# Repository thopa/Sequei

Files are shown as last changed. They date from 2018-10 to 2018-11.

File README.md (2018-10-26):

# Sequei
Arduino analog pot controlled drum machine based on the concept of Mutable Instrument's Anushri and Grids drum sequencer.

Features:

4 trigger drum Channels with Density and X Y drum mapping (see Mutable Instruments Grids)
Clock Sync
Control Voltage over Map X and Map Y

Special thanks to:
Olivier Gillet (olivier@mutable-instruments.net)
Honza Hrubes /aka ashimoke ashimoke@gmail.com
Geert @ http://Goltstein.nl
Darwin Grosse @  (www.20objects.com).

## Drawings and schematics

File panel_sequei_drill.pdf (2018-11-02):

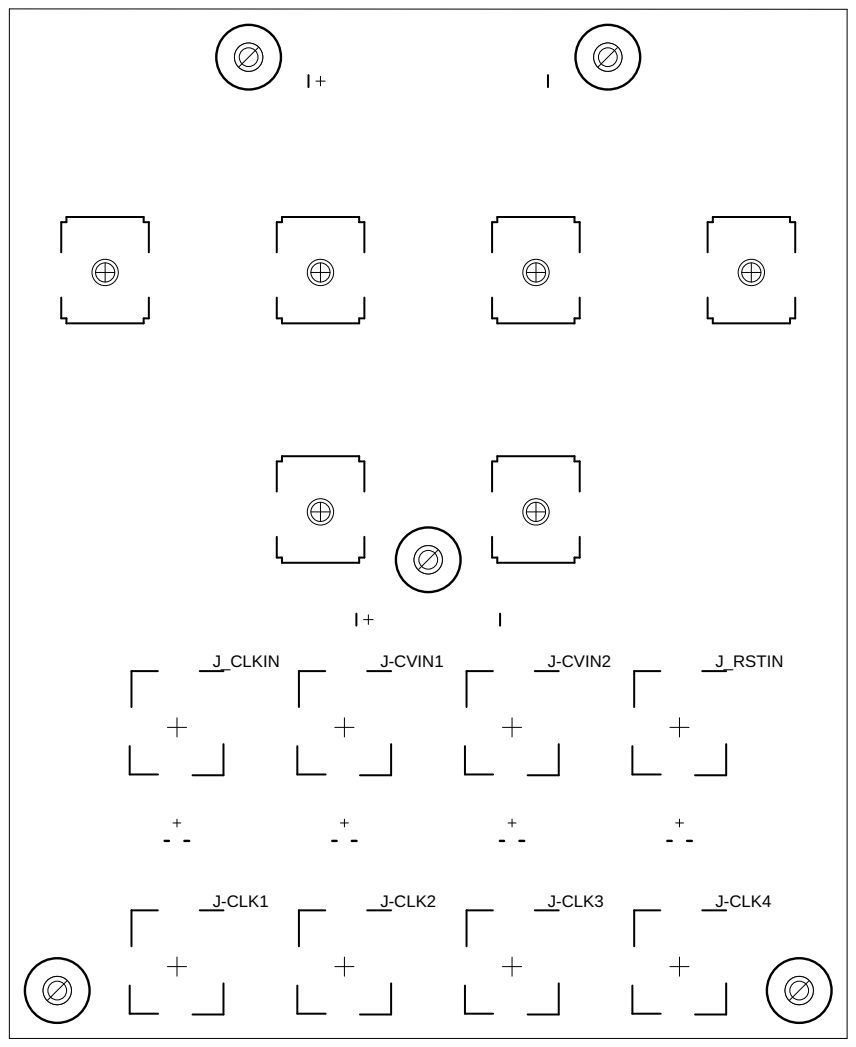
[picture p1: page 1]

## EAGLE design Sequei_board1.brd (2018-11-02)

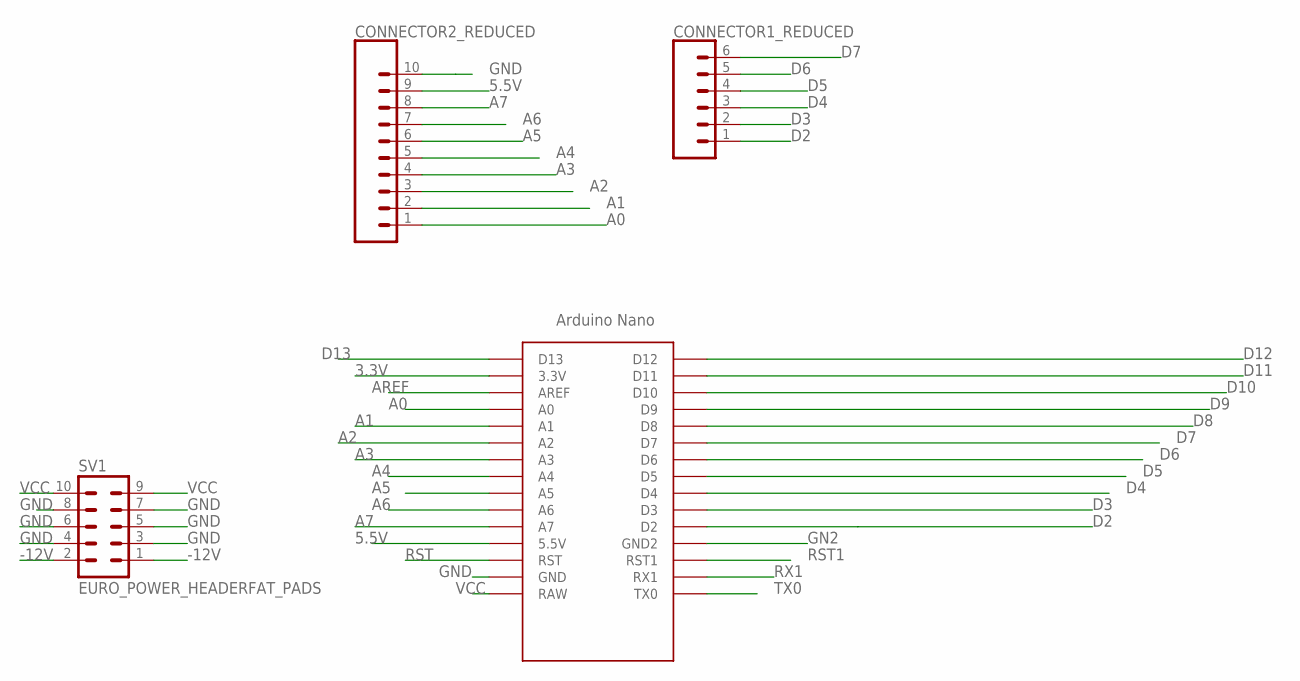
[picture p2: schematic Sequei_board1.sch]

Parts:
CONNECTOR1_REDUCED: CONN_06LONGPADS; 1X06_LONGPADS
CONNECTOR2_REDUCED: CONN_10_LONGPADS10_LONGPADS; 1X10_LONGPADS
SV1: EURO_POWER_HEADERFAT_PADS; EURO_PWR_HEADER_FAT
U$1: NANO

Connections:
3.3V: U$1.3.3V
5.5V: CONNECTOR2_REDUCED.9, U$1.5V (5.5V)
-12V: SV1.1, SV1.2
A0: CONNECTOR2_REDUCED.1, U$1.A0
A1: CONNECTOR2_REDUCED.2, U$1.A1
A2: CONNECTOR2_REDUCED.3, U$1.A2
A3: CONNECTOR2_REDUCED.4, U$1.A3
A4: CONNECTOR2_REDUCED.5, U$1.A4
A5: CONNECTOR2_REDUCED.6, U$1.A5
A6: CONNECTOR2_REDUCED.7, U$1.A6
A7: CONNECTOR2_REDUCED.8, U$1.A7
AREF: U$1.AREF
D2: CONNECTOR1_REDUCED.1, U$1.D2
D3: CONNECTOR1_REDUCED.2, U$1.D3
D4: CONNECTOR1_REDUCED.3, U$1.D4
D5: CONNECTOR1_REDUCED.4, U$1.D5
D6: CONNECTOR1_REDUCED.5, U$1.D6
D7: CONNECTOR1_REDUCED.6, U$1.D7
D8: U$1.D8
D9: U$1.D9
D10: U$1.D10
D11: U$1.D11
D12: U$1.D12
D13: U$1.D13
GN2: U$1.GND1 (GND2)
GND: CONNECTOR2_REDUCED.10, SV1.3, SV1.4, SV1.5, SV1.6, SV1.7, SV1.8, U$1.GND
RST: U$1.RST
RST1: U$1.RST1
RX1: U$1.RX1
TX0: U$1.TX0
VCC: SV1.9, SV1.10, U$1.RAW

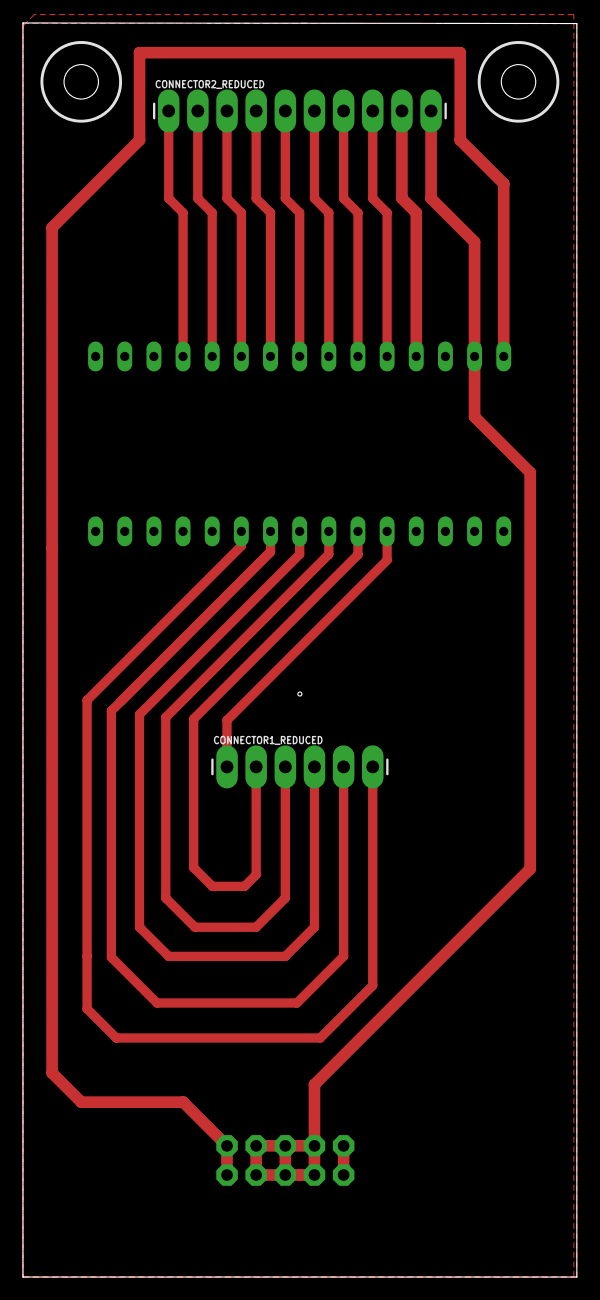
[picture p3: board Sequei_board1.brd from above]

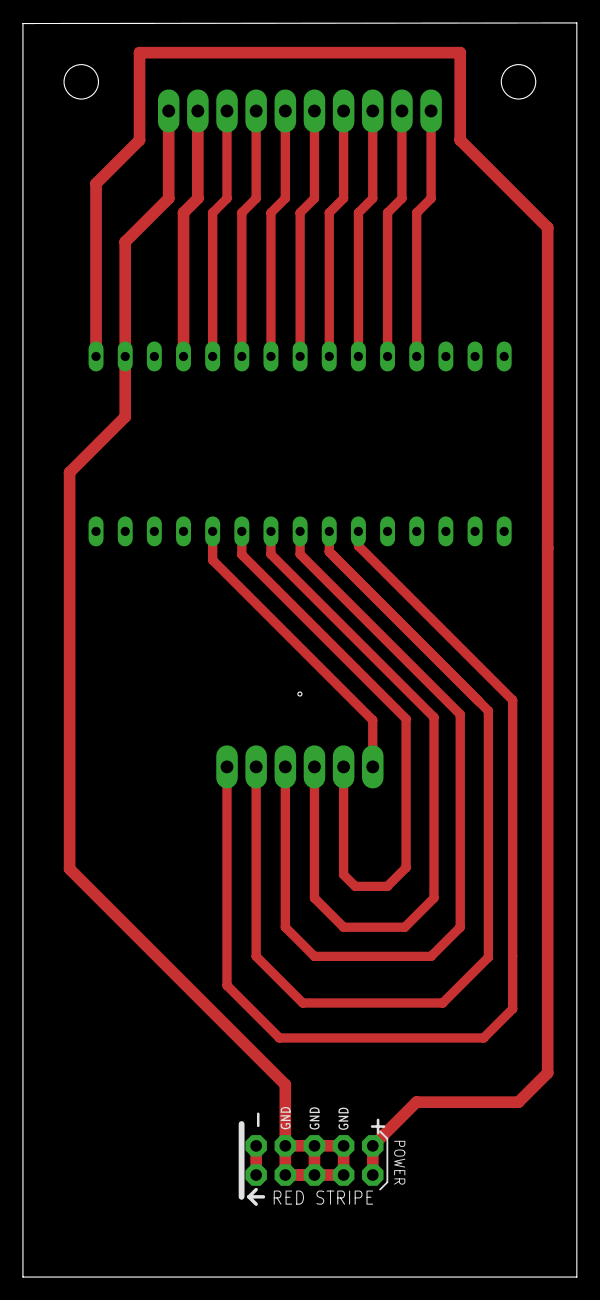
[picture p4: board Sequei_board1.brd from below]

Board: 2 copper layers, 48.3 x 109.3 mm, 6 parts (2 on the bottom side), 18 nets.

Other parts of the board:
H1, H2: DRIL-3

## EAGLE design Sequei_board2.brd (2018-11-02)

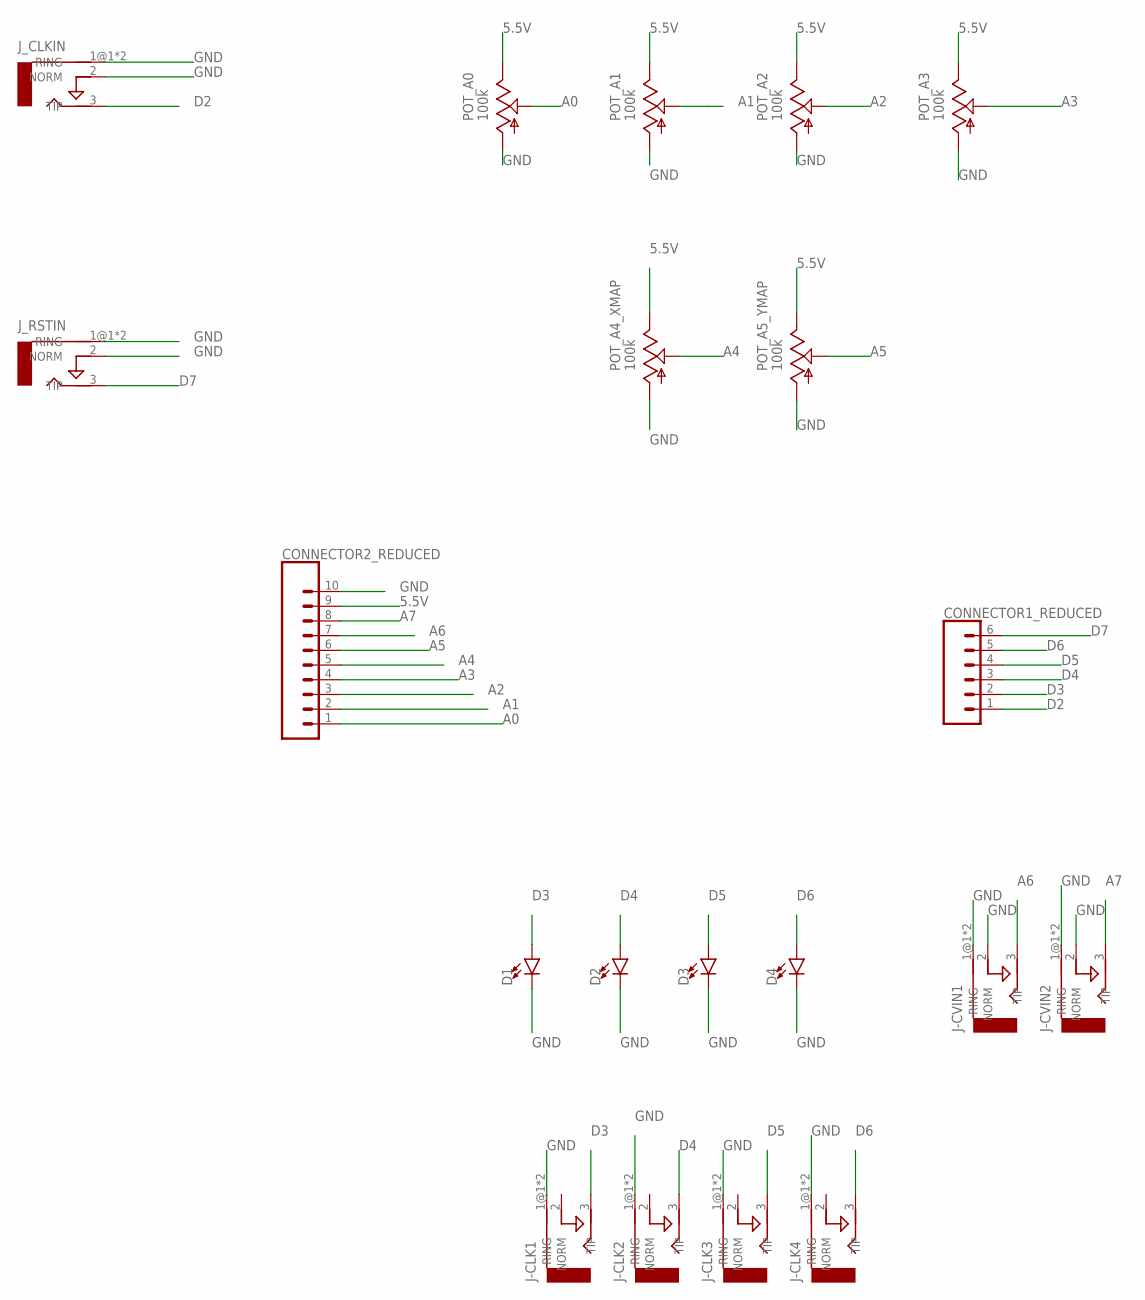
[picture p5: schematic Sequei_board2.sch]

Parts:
CONNECTOR1_REDUCED: CONN_06LONGPADS; 1X06_LONGPADS
CONNECTOR2_REDUCED: CONN_10_LONGPADS10_LONGPADS; 1X10_LONGPADS
D1, D2, D3, D4: LED-3MM-NO_SILK; LED_3MM-NS
J-CLK1, J-CLK2, J-CLK3, J-CLK4: AUDIO-JACKERTHENVAR; ERTHENVAR-JACK
J-CVIN1, J-CVIN2: AUDIO-JACKERTHENVAR; ERTHENVAR-JACK
J_CLKIN: AUDIO-JACKERTHENVAR; ERTHENVAR-JACK
J_RSTIN: AUDIO-JACKERTHENVAR; ERTHENVAR-JACK
POT_A0, POT_A1, POT_A2, POT_A3, POT_A4_XMAP, POT_A5_YMAP: 100k; 9MM_SNAP-IN_POT

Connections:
5.5V: CONNECTOR2_REDUCED.9, POT_A0.3 (E), POT_A1.3 (E), POT_A2.3 (E), POT_A3.3 (E), POT_A4_XMAP.3 (E), POT_A5_YMAP.3 (E)
A0: CONNECTOR2_REDUCED.1, POT_A0.2 (S)
A1: CONNECTOR2_REDUCED.2, POT_A1.2 (S)
A2: CONNECTOR2_REDUCED.3, POT_A2.2 (S)
A3: CONNECTOR2_REDUCED.4, POT_A3.2 (S)
A4: CONNECTOR2_REDUCED.5, POT_A4_XMAP.2 (S)
A5: CONNECTOR2_REDUCED.6, POT_A5_YMAP.2 (S)
A6: CONNECTOR2_REDUCED.7, J-CVIN1.3 (TIP)
A7: CONNECTOR2_REDUCED.8, J-CVIN2.3 (TIP)
D2: CONNECTOR1_REDUCED.1, J_CLKIN.3 (TIP)
D3: CONNECTOR1_REDUCED.2, D1.A, J-CLK1.3 (TIP)
D4: CONNECTOR1_REDUCED.3, D2.A, J-CLK2.3 (TIP)
D5: CONNECTOR1_REDUCED.4, D3.A, J-CLK3.3 (TIP)
D6: CONNECTOR1_REDUCED.5, D4.A, J-CLK4.3 (TIP)
D7: CONNECTOR1_REDUCED.6, J_RSTIN.3 (TIP)
GND: CONNECTOR2_REDUCED.10, D1.K (C), D2.K (C), D3.K (C), D4.K (C), J-CLK1.1@1 (RING), J-CLK1.1@2 (RING), J-CLK2.1@1 (RING), J-CLK2.1@2 (RING), J-CLK3.1@1 (RING), J-CLK3.1@2 (RING), J-CLK4.1@1 (RING), J-CLK4.1@2 (RING), J-CVIN1.1@1 (RING), J-CVIN1.1@2 (RING), J-CVIN1.2 (NORM), J-CVIN2.1@1 (RING), J-CVIN2.1@2 (RING), J-CVIN2.2 (NORM), J_CLKIN.1@1 (RING), J_CLKIN.1@2 (RING), J_CLKIN.2 (NORM), J_RSTIN.1@1 (RING), J_RSTIN.1@2 (RING), J_RSTIN.2 (NORM), POT_A0.1 (A), POT_A1.1 (A), POT_A2.1 (A), POT_A3.1 (A), POT_A4_XMAP.1 (A), POT_A5_YMAP.1 (A)

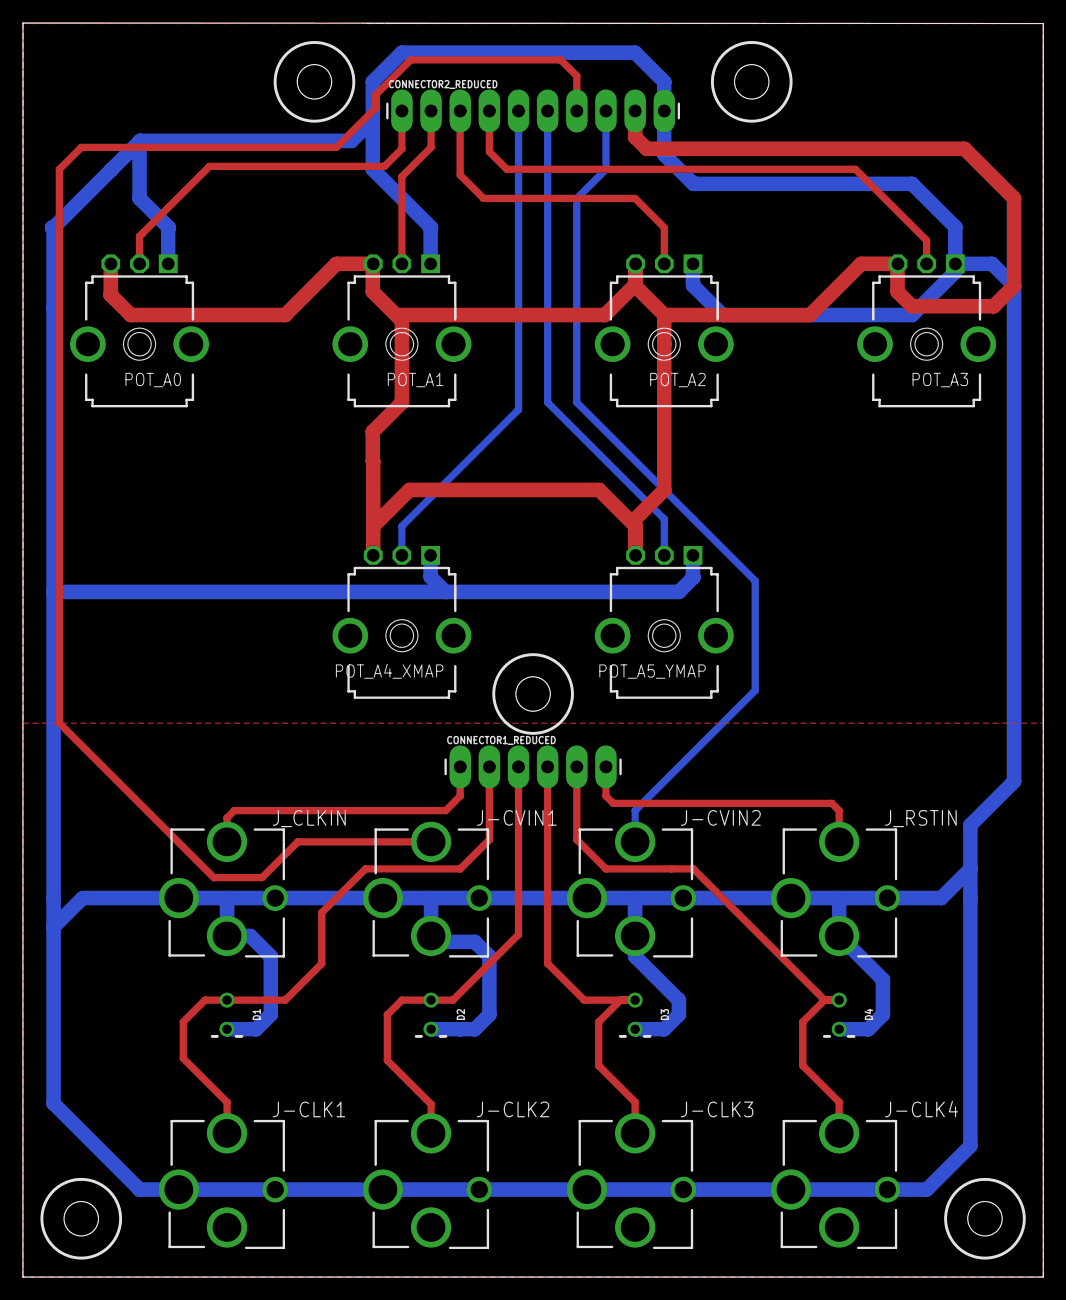
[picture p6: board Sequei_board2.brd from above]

Board: 2 copper layers, 88.9 x 109.3 mm, 25 parts (0 on the bottom side), 16 nets.

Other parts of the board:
H1, H2, H3, H4, H5: DRIL-3

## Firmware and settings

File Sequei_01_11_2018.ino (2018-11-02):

//Arduino Trigger Sequencer bases on Mutable Instruments Anushri and Grids by Thopa 2018 djthopa@djthopa.net
//
// 4 trigger Channels synced to Analog Clock

//Special thanks to:
//Olivier Gillet (olivier@mutable-instruments.net)

//Honza Hrubes /aka ashimoke ashimoke@gmail.com

//Geert @ http://Goltstein.nl

//Darwin Grosse @  (www.20objects.com).

///////////////////////////////////////////////////////////////////////////////////////////////////////////

// Controls:

//Bass drum density pot  ---> A0
//Snare drum density pot ---> A1
//HiHat density pot      ---> A2
//OhHat density pot      ---> A3

//X coordinate           ---> A4
//Y coordinate           ---> A5

//Control Voltage over X coordinate          ---> A6
//Control Voltage over Y coordinate          ---> A7
// TO DO :

// Add cv control over Density & X - Y Coordinates
// Reset seems to be not working properly


//// copied from grids

int BDcluster1[16] = {255, 0, 0, 0, 0, 0, 145, 0, 0, 0, 0, 0, 218, 0, 0, 0 };
int SDcluster1[16] = {72, 0, 36, 0, 182, 0, 0, 0, 109, 0, 0, 0, 72, 0, 0, 0 };
int HHcluster1[16] = {36, 0, 109, 0, 0, 0, 8, 0, 255, 0, 0, 0, 0, 0, 72, 0 };
int OHcluster1[16] = {0, 0, 182, 0, 0, 0, 36, 0, 218, 0, 0, 0, 145, 0, 0, 0 };

int BDcluster2[16] = {229, 0, 25, 0, 102, 0, 25, 0, 204, 0, 25, 0, 76, 0, 8, 0 };
int SDcluster2[16] = {255, 0, 8, 0, 51, 0, 25, 0, 178, 0, 25, 0, 153, 0, 127, 0 };
int HHcluster2[16] = {28, 0, 198, 0, 56, 0, 56, 0, 226, 0, 28, 0, 141, 0, 28, 0 };
int OHcluster2[16] = {28, 0, 170, 0, 28, 0, 28, 0, 255, 0, 113, 0, 85, 0, 85, 0 };

int BDcluster3[16] = {255, 0, 0, 0, 127, 0, 0, 0, 0, 0, 102, 0, 0, 0, 229, 0 };
int SDcluster3[16] = {0, 0, 178, 0, 204, 0, 0, 0, 76, 0, 51, 0, 153, 0, 25, 0 };
int HHcluster3[16] = {0, 0, 127, 0, 0, 0, 0, 0, 255, 0, 191, 0, 31, 0, 63, 0 };
int OHcluster3[16] = {0, 0, 95, 0, 0, 0, 0, 0, 223, 0, 0, 0, 31, 0, 159, 0 };

int BDcluster4[16] = {255, 0, 212, 0, 63, 0, 0, 0, 106, 0, 148, 0, 85, 0, 127, 0 };
int SDcluster4[16] = {191, 0, 21, 0, 233, 0, 0, 0, 21, 0, 170, 0, 0, 0, 42, 0 };
int HHcluster4[16] = {0, 0, 0, 0, 141, 0, 113, 0, 255, 0, 198, 0, 0, 0, 56, 0 };
int OHcluster4[16] = {0, 0, 85, 0, 56, 0, 28, 0, 226, 0, 28, 0, 170, 0, 56, 0 };

int BDcluster5[16] = {255, 0, 31, 0, 63, 0, 63, 0, 127, 0, 95, 0, 191, 0, 63, 0 };
int SDcluster5[16] = {223, 0, 31, 0, 159, 0, 63, 0, 31, 0, 63, 0, 95, 0, 31, 0 };
int HHcluster5[16] = {8, 0, 0, 0, 95, 0, 63, 0, 255, 0, 0, 0, 127, 0, 0, 0 };
int OHcluster5[16] = {8, 0, 0, 0, 159, 0, 63, 0, 255, 0, 223, 0, 191, 0, 31, 0 };

int BDcluster6[16] = {255, 0, 51, 0, 25, 0, 76, 0, 0, 0, 0, 0, 102, 0, 0, 0 };
int SDcluster6[16] = {204, 0, 229, 0, 0, 0, 178, 0, 0, 0, 153, 0, 127, 0, 8, 0 };
int HHcluster6[16] = {178, 0, 127, 0, 153, 0, 204, 0, 255, 0, 0, 0, 25, 0, 76, 0 };
int OHcluster6[16] = {102, 0, 51, 0, 0, 0, 0, 0, 229, 0, 25, 0, 25, 0, 204, 0 };

int BDcluster7[16] = {255, 0, 0, 0, 223, 0, 0, 0, 31, 0, 8, 0, 127, 0, 0, 0 };
int SDcluster7[16] = {95, 0, 0, 0, 159, 0, 0, 0, 95, 0, 63, 0, 191, 0, 0, 0 };
int HHcluster7[16] = {51, 0, 204, 0, 0, 0, 102, 0, 255, 0, 127, 0, 8, 0, 178, 0 };
int OHcluster7[16] = {25, 0, 229, 0, 0, 0, 76, 0, 204, 0, 153, 0, 51, 0, 25, 0 };

int BDcluster8[16] = {223, 0, 0, 0, 63, 0, 0, 0, 95, 0, 0, 0, 223, 0, 31, 0 };
int SDcluster8[16] = {255, 0, 0, 0, 159, 0, 0, 0, 127, 0, 31, 0, 191, 0, 31, 0 };
int HHcluster8[16] = {0, 0, 0, 0, 109, 0, 0, 0, 218, 0, 0, 0, 182, 0, 72, 0 };
int OHcluster8[16] = {8, 0, 36, 0, 145, 0, 36, 0, 255, 0, 8, 0, 182, 0, 72, 0 };

int BDcluster9[16] = {255, 0, 0, 0, 218, 0, 0, 0, 36, 0, 0, 0, 218, 0, 0, 0 };
int SDcluster9[16] = {182, 0, 109, 0, 255, 0, 0, 0, 0, 0, 0, 0, 145, 0, 72, 0 };
int HHcluster9[16] = {159, 0, 0, 0, 31, 0, 127, 0, 255, 0, 31, 0, 0, 0, 95, 0 };
int OHcluster9[16] = {8, 0, 0, 0, 191, 0, 31, 0, 255, 0, 31, 0, 223, 0, 63, 0 };

int BDfreq = 0;
int SDfreq = 0;
int HHfreq = 0;
int OHfreq = 0; // variables for storing drum density

float Xmap = 0;
float Ymap = 0;                          // coordinates of the 2D pattern map

//  variables for interrupt handling of the clock input
volatile int clkState = LOW;


byte reset_current;
byte reset_previous;

int tempo = 120;

const int clkIn = 2;           // the digital (clock) input
const int rstClkIn = 7;       // The Reset Clock Input // Need to change this to 7 as used on Euclidean template
const int trigTime = 25;       // 25 ms trigger timing

unsigned long digMilli[2] = {0, 0};  // a place to store millis()



const int BDrum_Out = 3;
const int SDrum_Out = 4;
const int HHats_out = 5;
const int OHats_out = 6;


int Position = 0;

int Sector = 0;                          // I have no idea what I'm doing... but it works... in a way.
float BDrum = 0;
float SDrum = 0;
float HHats = 0;
float OHats = 0;

int tempoLED = 13;


void setup() {

  Serial.begin(9600);

  // set up the digital (clock) input
  pinMode(clkIn, INPUT);

  pinMode(rstClkIn, INPUT_PULLUP);

  /// Setup the Drum Out Pins

  pinMode(BDrum_Out, OUTPUT);
  digitalWrite(BDrum_Out, LOW);

  pinMode(SDrum_Out, OUTPUT);
  digitalWrite(SDrum_Out, LOW);

  pinMode(HHats_out, OUTPUT);
  digitalWrite(HHats_out, LOW);

  pinMode(OHats_out, OUTPUT);
  digitalWrite(OHats_out, LOW);

  pinMode(A6, INPUT);
  pinMode(A7, INPUT);


  // Note: Interrupt 0 is for pin 2 (clkIn)
  attachInterrupt(0, isr, RISING);
}

void isr()
{
  clkState = HIGH;
}



void loop() {


  if (clkState == HIGH) {

    clkState = LOW;
    digMilli[0] = millis();
    //tempo = analogRead(0) >> 7;

    //

    BDfreq = analogRead(A0);                              // read bass drum density pot
    BDfreq = map(BDfreq, 0, 1023, 255, 0);                // remap it to values similar to those in cluster configurations
    SDfreq = analogRead(A1);                              // read snare drum density pot
    SDfreq = map(SDfreq, 0, 1023, 255, 0);                // remap it to values similar to those in cluster configurations
    HHfreq = analogRead(A2);                              // read hi hat density pot
    HHfreq = map(HHfreq, 0, 1023, 255, 0);                // remap it to values similar to those in cluster configurations
    OHfreq = analogRead(A3);                              // read hi hat density pot
    OHfreq = map(OHfreq, 0, 1023, 255, 0);                // remap it to values similar to those in cluster configurations

    // read the X-pot for cluster navigation
    Xmap = analogRead(A4) + ((analogRead(A6) >> 2));     //Added External Cv control
    Serial.print("Xmap");
    Serial.print(Xmap);
    Xmap = map(Xmap, 0, 1023, -100, 100);                 // remap around zero

    // read the Y-pot for cluster navigation
    Ymap = analogRead(A5) + ((analogRead(A7) >> 2));       //Added External Cv control
    Serial.print("  Ymap");
    Serial.println(Ymap);
    Ymap = map(Ymap, 0, 1023, -100, 100);                   // remap around zero

    if (Xmap < 0 && Ymap < 0) Sector = 1;
    if (Xmap < 0 && Ymap > 0) Sector = 2;
    if (Xmap >= 0 && Ymap >= 0) Sector = 3;
    if (Xmap >= 0 && Ymap <= 0) Sector = 4;               // determine sector - which 4 clusters do we want to interpolate

    Xmap = abs(Xmap / 100);
    Ymap = abs(Ymap / 100);                               // get rid off negative values and make it smaller


    if (Sector == 1) {
      SDrum = ( ( (SDcluster1[Position] * Xmap) + (SDcluster2[Position] * (1 - Xmap) ) ) * Ymap ) + ( ( (SDcluster4[Position] * Xmap) + (SDcluster5[Position] * (1 - Xmap) ) ) * ( 1 - Ymap) );
      BDrum = ( ( (BDcluster1[Position] * Xmap) + (BDcluster2[Position] * (1 - Xmap) ) ) * Ymap ) + ( ( (BDcluster4[Position] * Xmap) + (BDcluster5[Position] * (1 - Xmap) ) ) * ( 1 - Ymap) );
      HHats = ( ( (HHcluster1[Position] * Xmap) + (HHcluster2[Position] * (1 - Xmap) ) ) * Ymap ) + ( ( (HHcluster4[Position] * Xmap) + (HHcluster5[Position] * (1 - Xmap) ) ) * ( 1 - Ymap) );
      OHats = ( ( (OHcluster1[Position] * Xmap) + (OHcluster2[Position] * (1 - Xmap) ) ) * Ymap ) + ( ( (OHcluster4[Position] * Xmap) + (OHcluster5[Position] * (1 - Xmap) ) ) * ( 1 - Ymap) );
    }

    if (Sector == 2) {
      SDrum = ( ( (SDcluster4[Position] * Xmap) + (SDcluster5[Position] * (1 - Xmap) ) ) * (1 - Ymap ) ) + ( ( (SDcluster7[Position] * Xmap) + (SDcluster8[Position] * (1 - Xmap) ) ) * Ymap );
      BDrum = ( ( (BDcluster4[Position] * Xmap) + (BDcluster5[Position] * (1 - Xmap) ) ) * (1 - Ymap ) ) + ( ( (BDcluster7[Position] * Xmap) + (BDcluster8[Position] * (1 - Xmap) ) ) * Ymap );
      HHats = ( ( (HHcluster4[Position] * Xmap) + (HHcluster5[Position] * (1 - Xmap) ) ) * (1 - Ymap ) ) + ( ( (HHcluster7[Position] * Xmap) + (HHcluster8[Position] * (1 - Xmap) ) ) * Ymap );
      OHats = ( ( (OHcluster4[Position] * Xmap) + (OHcluster5[Position] * (1 - Xmap) ) ) * (1 - Ymap ) ) + ( ( (OHcluster7[Position] * Xmap) + (OHcluster8[Position] * (1 - Xmap) ) ) * Ymap );
    }

    if (Sector == 3) {
      SDrum = ( ( (SDcluster5[Position] * ( 1 - Xmap ) ) + (SDcluster6[Position] * Xmap ) ) * ( 1 - Ymap ) ) + ( ( (SDcluster8[Position] * ( 1 - Xmap )) + (SDcluster9[Position] * Xmap ) ) * Ymap );
      BDrum = ( ( (BDcluster5[Position] * ( 1 - Xmap ) ) + (BDcluster6[Position] * Xmap ) ) * ( 1 - Ymap ) ) + ( ( (BDcluster8[Position] * ( 1 - Xmap )) + (BDcluster9[Position] * Xmap ) ) * Ymap );
      HHats = ( ( (HHcluster5[Position] * ( 1 - Xmap ) ) + (HHcluster6[Position] * Xmap ) ) * ( 1 - Ymap ) ) + ( ( (HHcluster8[Position] * ( 1 - Xmap )) + (HHcluster9[Position] * Xmap ) ) * Ymap );
      OHats = ( ( (OHcluster5[Position] * ( 1 - Xmap ) ) + (OHcluster6[Position] * Xmap ) ) * ( 1 - Ymap ) ) + ( ( (OHcluster8[Position] * ( 1 - Xmap )) + (OHcluster9[Position] * Xmap ) ) * Ymap );
    }

    if (Sector == 4) {
      SDrum = ( ( (SDcluster2[Position] * ( 1 - Xmap ) ) + (SDcluster3[Position] * Xmap ) ) * Ymap ) + ( ( (SDcluster5[Position] * ( 1 - Xmap ) ) + (SDcluster6[Position] * Xmap ) ) * ( 1 - Ymap) );
      BDrum = ( ( (BDcluster2[Position] * ( 1 - Xmap ) ) + (BDcluster3[Position] * Xmap ) ) * Ymap ) + ( ( (BDcluster5[Position] * ( 1 - Xmap ) ) + (BDcluster6[Position] * Xmap ) ) * ( 1 - Ymap) );
      HHats = ( ( (HHcluster2[Position] * ( 1 - Xmap ) ) + (HHcluster3[Position] * Xmap ) ) * Ymap ) + ( ( (HHcluster5[Position] * ( 1 - Xmap ) ) + (HHcluster6[Position] * Xmap ) ) * ( 1 - Ymap) );
      OHats = ( ( (OHcluster2[Position] * ( 1 - Xmap ) ) + (OHcluster3[Position] * Xmap ) ) * Ymap ) + ( ( (OHcluster5[Position] * ( 1 - Xmap ) ) + (OHcluster6[Position] * Xmap ) ) * ( 1 - Ymap) );
    }

    ///////////////////////////////// above are the equations for interpolating between values. Nothing fancy.


    if (BDrum > BDfreq) digitalWrite(BDrum_Out, HIGH);


    if (SDrum > SDfreq) digitalWrite(SDrum_Out, HIGH);


    if (HHats > HHfreq) digitalWrite(HHats_out, HIGH);


    if (OHats > OHfreq) digitalWrite(OHats_out, HIGH);


    Position = Position + 1;                                    // increase the step count

    digitalWrite(tempoLED, HIGH);                               // blink led every step
    delay(20);
    digitalWrite(tempoLED, LOW);

    //delay(tempo);                                               // step lenght



    // Turn the off the Digital Outs
    for (int i = 0; i < 2; i++) {
      if ((millis() - digMilli[i] > trigTime)) {
        digitalWrite(BDrum_Out, LOW);
        digitalWrite(SDrum_Out, LOW);
        digitalWrite(HHats_out, LOW);
        digitalWrite(OHats_out, LOW);
      }
    }

    if (Position > 16) {// This resets to step 1
      Position = 0;

      reset_current = digitalRead(rstClkIn);

      if (reset_current != reset_previous) {
        reset_previous = reset_current;

        if (reset_current == 1) {
          Position = 0;
        }


        // Read the Pot Values for debugging // Comment out if not Debugging

        // Serial.print(analogRead(0));   // print the A2 input
        //Serial.print('\t');            // print a tab character
        //Serial.print(analogRead(1));   // print the A2 input
        //Serial.print('\t');            // print a tab character
        //Serial.print(analogRead(2));   // print the A2 input
        //Serial.print('\t');            // print a tab character
        //Serial.print(analogRead(3));   // print the A3 input
        //Serial.print('\t');            // print a tab character
        //Serial.print(analogRead(4));   // print the A3 input
        //Serial.print('\t');            // print a tab character
        //Serial.print(analogRead(5));   // print the A3 input
        //Serial.println();              // line feed
      }
    }
  }
}

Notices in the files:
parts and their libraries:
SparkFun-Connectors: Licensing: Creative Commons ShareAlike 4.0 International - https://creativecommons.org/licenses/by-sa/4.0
